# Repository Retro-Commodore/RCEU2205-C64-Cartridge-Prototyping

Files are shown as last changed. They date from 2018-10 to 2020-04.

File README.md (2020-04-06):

# RCEU2205 - C64 Cartridge Prototyping
A prototyping cartridge with cart connectors and/or header pins

With this you can add cartridge edge connectors and/or header pins, quite useful for doing diagnostics or other kinds of fun with the Commodore 64/128 cartridge port.

Component list, recommended but not required
* DIL/SIL headers 2.54mm pitch
* 44pin Edge connector 2.54mm pitch, vertical and/or horizontal

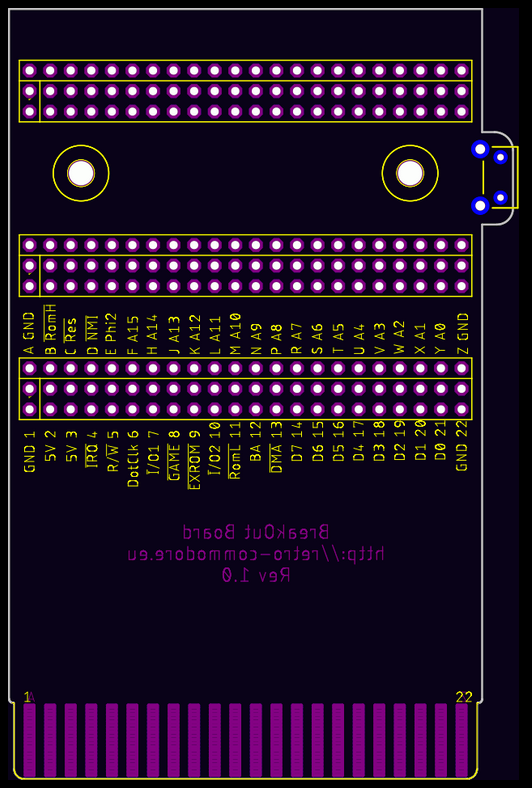
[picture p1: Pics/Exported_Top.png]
RCEU2205 Cartridge Prototyping


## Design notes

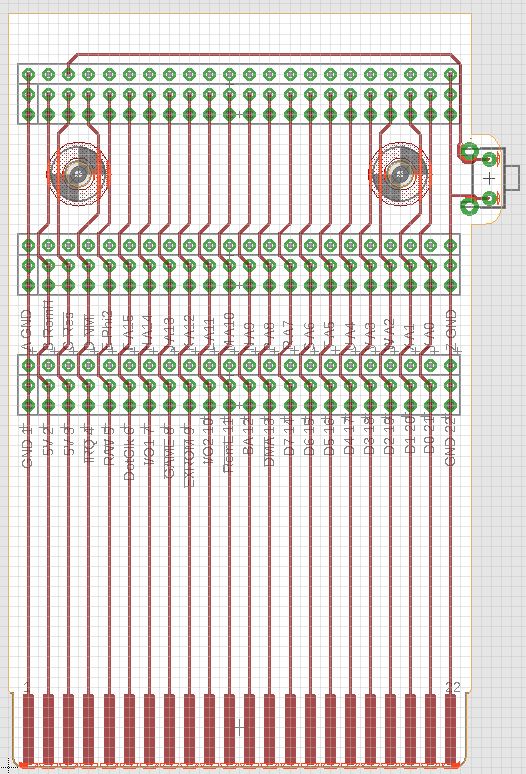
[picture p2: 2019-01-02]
Pics/top.jpg

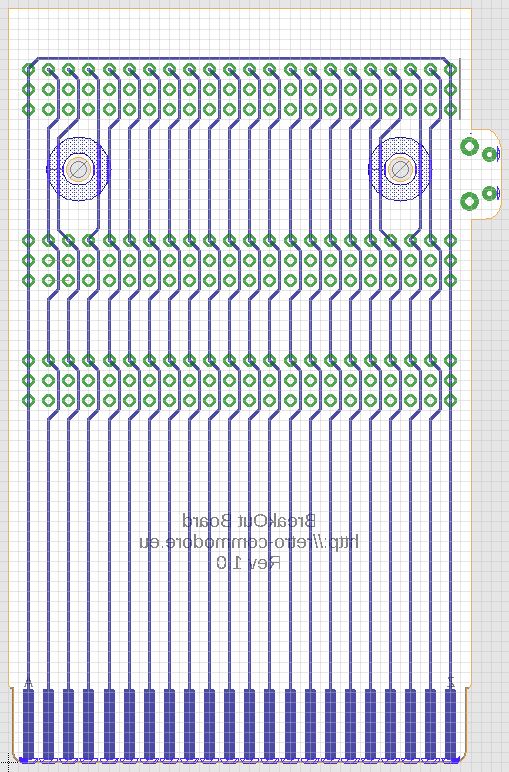
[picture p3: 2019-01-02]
Pics/bottom.jpg

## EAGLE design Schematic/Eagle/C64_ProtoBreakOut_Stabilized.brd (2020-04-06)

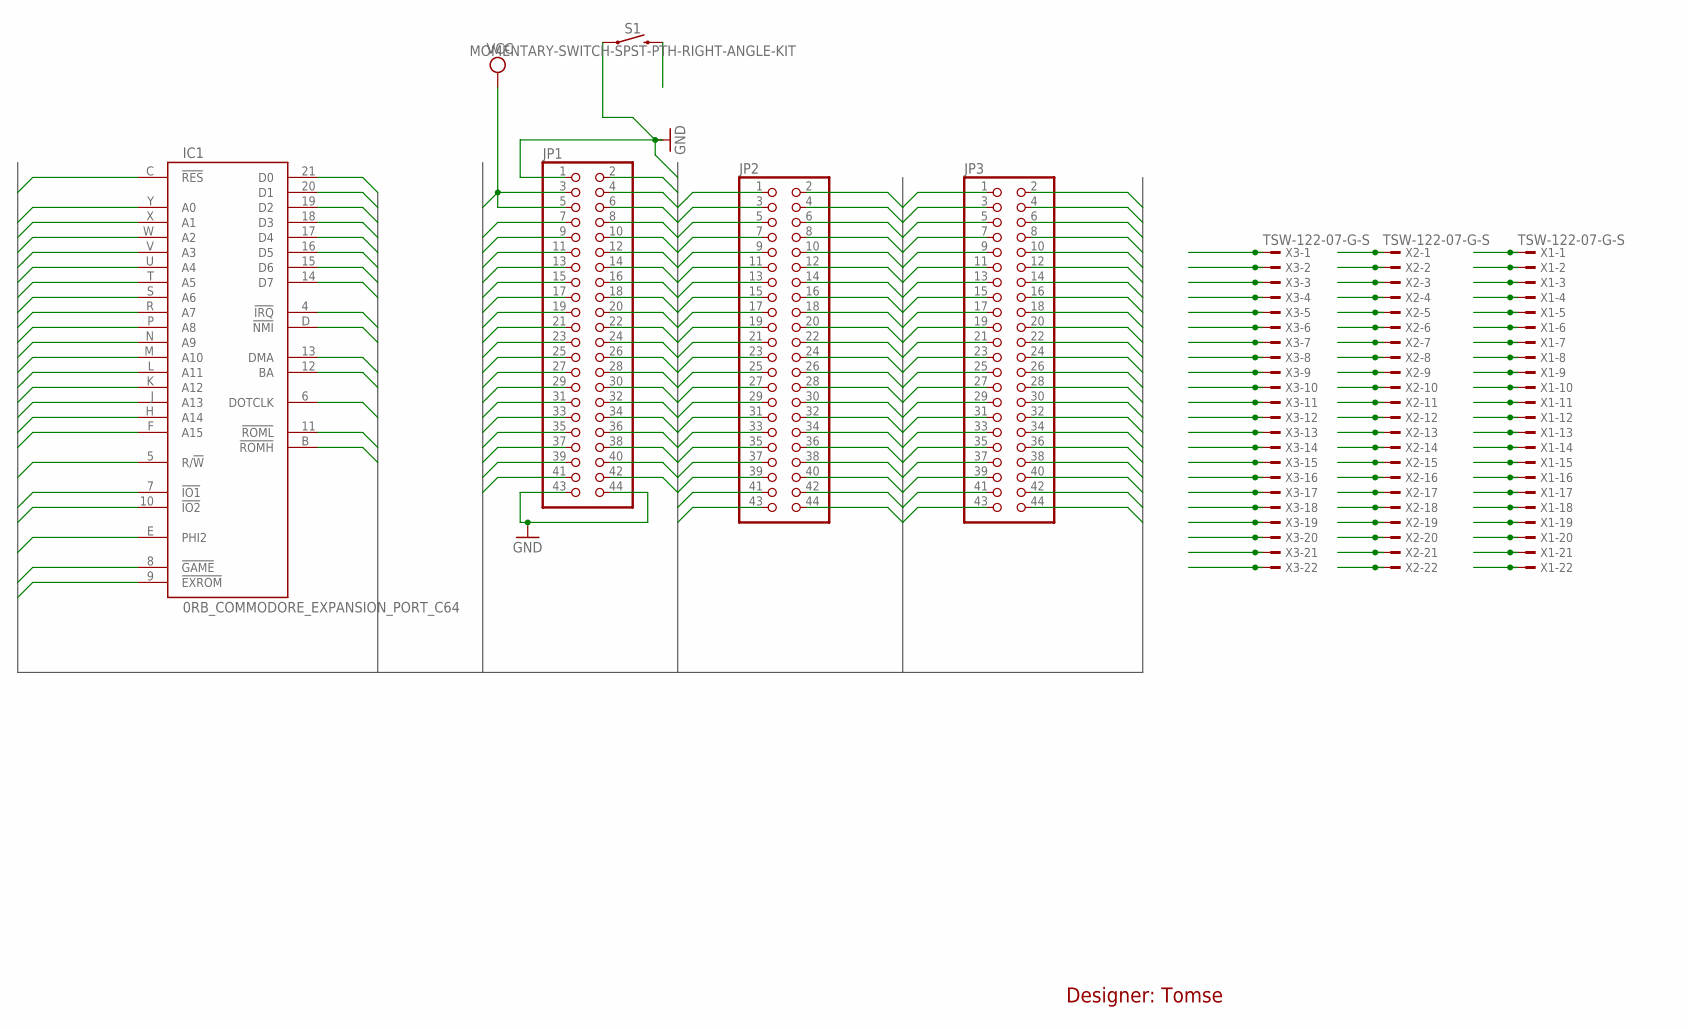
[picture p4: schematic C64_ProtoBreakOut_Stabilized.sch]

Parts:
IC1: 0RB_COMMODORE_EXPANSION_PORT_C64; 0RB_COMMODORE_MA100-22-2
JP1, JP2, JP3: PINHD-2X22; 2X22
S1: MOMENTARY-SWITCH-SPST-PTH-RIGHT-ANGLE-KIT; TACTILE_SWITCH_PTH_RIGHT_ANGLE_KIT
X1, X2, X3: TSW-122-07-G-S; TSW-122-XX-G-S

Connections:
!DMA: IC1.13 (DMA), JP1.25, JP2.25, JP3.25, X1.13, X2.13, X3.13
!EXROM: IC1.9 (!EXROM), JP1.17, JP2.17, JP3.17, X1.9, X2.9, X3.9
!GAME: IC1.8 (!GAME), JP1.15, JP2.15, JP3.15, X1.8, X2.8, X3.8
!IO1: IC1.7 (!IO1), JP1.13, JP2.13, JP3.13, X1.7, X2.7, X3.7
!IO2: IC1.10 (!IO2), JP1.19, JP2.19, JP3.19, X1.10, X2.10, X3.10
!IRQ: IC1.4 (!IRQ), JP1.7, JP2.7, JP3.7, X1.4, X2.4, X3.4
!NMI: IC1.D (!NMI), JP1.8, JP2.8, JP3.8
!RES: IC1.C (!RES), JP1.6, JP2.6, JP3.6, S1.2
!ROMH: IC1.B (!ROMH), JP1.4, JP2.4, JP3.4
!ROML: IC1.11 (!ROML), JP1.21, JP2.21, JP3.21, X1.11, X2.11, X3.11
A0: IC1.Y (A0), JP1.42, JP2.42, JP3.42
A1: IC1.X (A1), JP1.40, JP2.40, JP3.40
A2: IC1.W (A2), JP1.38, JP2.38, JP3.38
A3: IC1.V (A3), JP1.36, JP2.36, JP3.36
A4: IC1.U (A4), JP1.34, JP2.34, JP3.34
A5: IC1.T (A5), JP1.32, JP2.32, JP3.32
A6: IC1.S (A6), JP1.30, JP2.30, JP3.30
A7: IC1.R (A7), JP1.28, JP2.28, JP3.28
A8: IC1.P (A8), JP1.26, JP2.26, JP3.26
A9: IC1.N (A9), JP1.24, JP2.24, JP3.24
A10: IC1.M (A10), JP1.22, JP2.22, JP3.22
A11: IC1.L (A11), JP1.20, JP2.20, JP3.20
A12: IC1.K (A12), JP1.18, JP2.18, JP3.18
A13: IC1.J (A13), JP1.16, JP2.16, JP3.16
A14: IC1.H (A14), JP1.14, JP2.14, JP3.14
A15: IC1.F (A15), JP1.12, JP2.12, JP3.12
BA: IC1.12 (BA), JP1.23, JP2.23, JP3.23, X1.12, X2.12, X3.12
D0: IC1.21 (D0), JP1.41, JP2.41, JP3.41, X1.21, X2.21, X3.21
D1: IC1.20 (D1), JP1.39, JP2.39, JP3.39, X1.20, X2.20, X3.20
D2: IC1.19 (D2), JP1.37, JP2.37, JP3.37, X1.19, X2.19, X3.19
D3: IC1.18 (D3), JP1.35, JP2.35, JP3.35, X1.18, X2.18, X3.18
D4: IC1.17 (D4), JP1.33, JP2.33, JP3.33, X1.17, X2.17, X3.17
D5: IC1.16 (D5), JP1.31, JP2.31, JP3.31, X1.16, X2.16, X3.16
D6: IC1.15 (D6), JP1.29, JP2.29, JP3.29, X1.15, X2.15, X3.15
D7: IC1.14 (D7), JP1.27, JP2.27, JP3.27, X1.14, X2.14, X3.14
DOTCLK: IC1.6 (DOTCLK), JP1.11, JP2.11, JP3.11, X1.6, X2.6, X3.6
GND: IC1.1 (GND), IC1.22 (GND), IC1.A (GND), IC1.Z (GND), JP1.1, JP1.2, JP1.43, JP1.44, JP2.1, JP2.2, JP2.43, JP2.44, JP3.1, JP3.2, JP3.43, JP3.44, S1.1, X1.1, X1.22, X2.1, X2.22, X3.1, X3.22
PHI2: IC1.E (PHI2), JP1.10, JP2.10, JP3.10
R!W: IC1.5 (R/!W), JP1.9, JP2.9, JP3.9, X1.5, X2.5, X3.5
VCC: IC1.2 (VCC), IC1.3 (VCC), JP1.3, JP1.5, JP2.3, JP2.5, JP3.3, JP3.5, X1.2, X1.3, X2.2, X2.3, X3.2, X3.3

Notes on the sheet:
Designer: Tomse

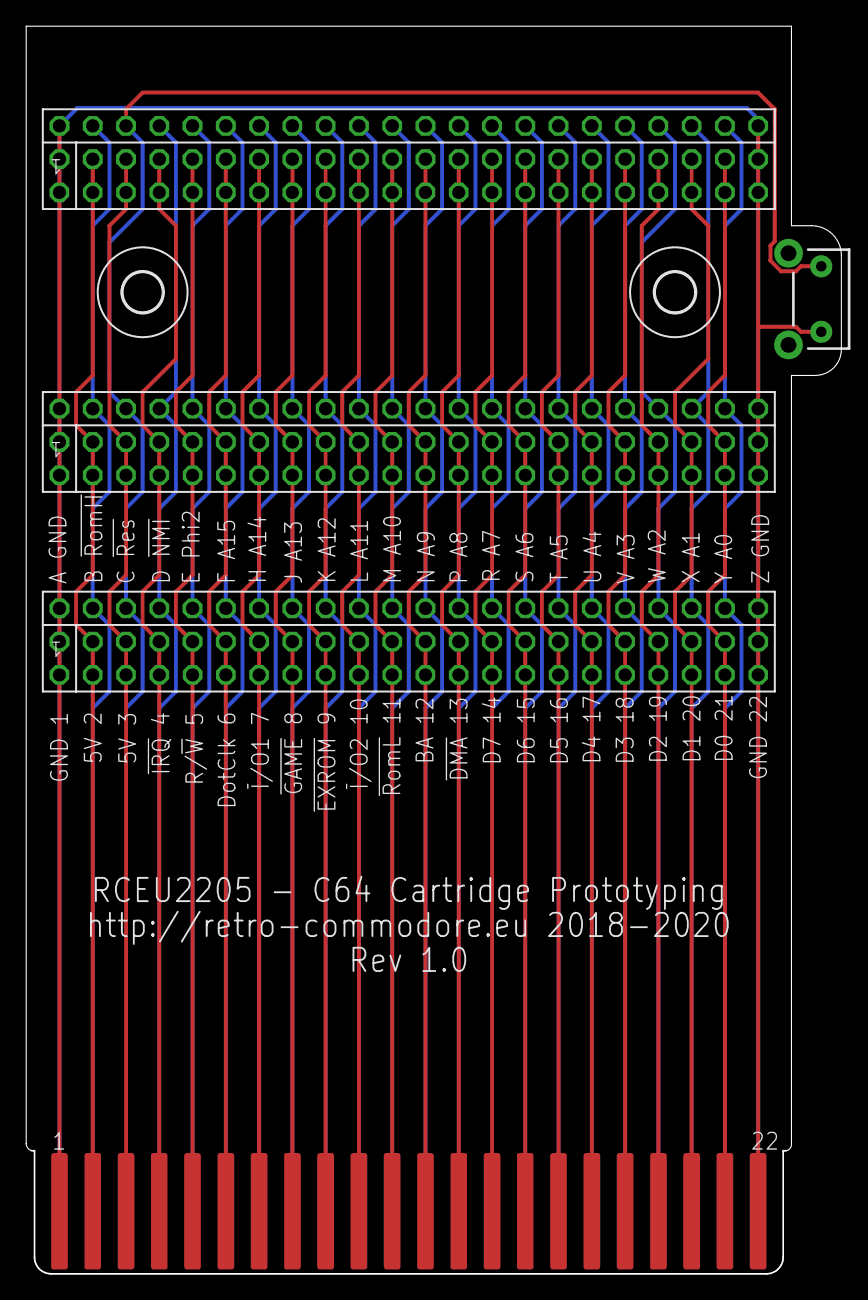
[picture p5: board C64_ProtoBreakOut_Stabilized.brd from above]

Board: 2 copper layers, 62.2 x 95.2 mm, 10 parts (0 on the bottom side), 40 nets.

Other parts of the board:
U$1, U$2: 3,0

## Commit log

2020-04-06 Fixing dirnaming
    [C64_ProtoBreakOut_Stabilized.brd, C64_ProtoBreakOut_Stabilized.sch]
2020-04-06 Cosmetic changes
    [C64_ProtoBreakOut_Stabilized.brd]

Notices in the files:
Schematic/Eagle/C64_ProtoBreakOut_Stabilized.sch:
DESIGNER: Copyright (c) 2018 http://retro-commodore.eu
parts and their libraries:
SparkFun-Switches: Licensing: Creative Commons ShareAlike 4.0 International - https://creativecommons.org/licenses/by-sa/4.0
